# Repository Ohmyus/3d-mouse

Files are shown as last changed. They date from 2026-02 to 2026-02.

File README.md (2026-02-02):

# 3d-mouse

This project contains the files, software and instructions to build your own 3D CAD mouse. This is a device that allows for seamless 6-DOF navigation on any popular CAD software, however, the commercial options are quite pricy, so we took it in or own hands to make a (much cheaper, at about 20€) DIY option, that works just like the 150€ product. If you are a maker that spends a lot of time in CAD, or work with CAD professionally, consider making yourself one of these!

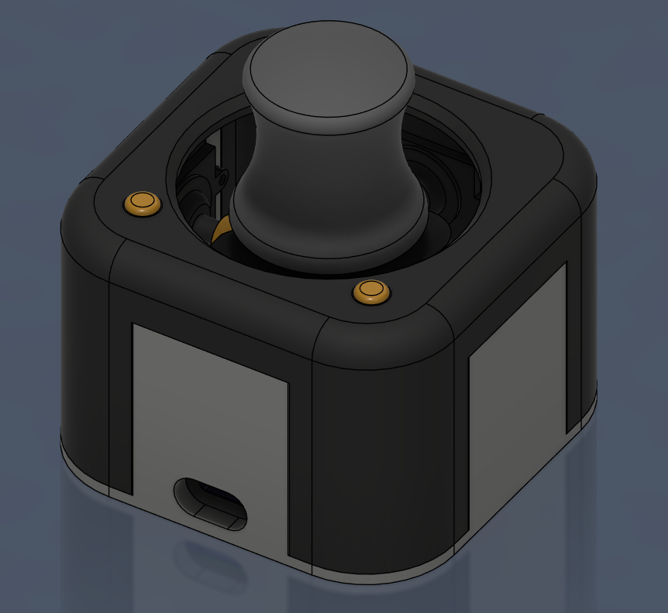
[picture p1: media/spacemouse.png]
Spacemouse


This spacemouse is a self-contained project. You are free to copy, modify, or add to it as you wish, as long as you credit its authors.

This project builds on [this](https://www.printables.com/model/864950-open-source-spacemouse-space-mushroom-remix) iteration of a 3D CAD mouse, by Teaching Tech. What we've done is created a new, smaller design, based on [these smaller joysticks](https://es.aliexpress.com/item/1005007021831547.html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) from the oculus controller. To interface with these joysticks, a PCB has been designed as well, that allows easier connection management, and the .grbr files are provided.

## Status:

A first prototype has been built, confirming that the PCB design is solid. All 6-DOF movements create their intended effect and allow for 3D navigation. No effort has been made yet to integrate the pushbuttons.

## Bill of Materials:

For each device that is built, the needed materials are:

 | Nº | Element | Quantity | Shopping link |
 | ---| ------- | -------- | ------------- |
 | 1  | Arduino Pro Micro | 1 | missing link |
 | 2  | Spacemouse PCB | 1 | missing link |
 | 3  | 3D printed parts | All | missing link |
 | 4  | 0.5 mm pitch, 5-pin ZIF connector | 4 | missing link |
 | 5  | Oculus Quest Joystick | 4 | missing link |
 | 6  | Wire | ~30 cm | missing link |
 | 7  | 6x6x4.3 mm pushbutton | 1 to 4 (user choice) | missing link |
 | 8  | 2-pin magnetic pogo connector| as many as pushbuttons | missing link |
 | 9  | USB cable (Arduino-Computer) | 1 | missing link |

## Build Instructions:
This section is still WIP. If possible, pictures will be added. Feedback is welcome.

## Required Tools:

- 3D printer (or the 3D printed parts)
- Soldering Iron
- Soldering flux
- Soldering Wick
- Tweezers (optional but *strongly* recommended)
- A computer that can flash an Arduino

### PCB & Electronics Assembly:
1.  Start by soldering all ZIF connectors to the PCB. The best results are obtained by using a lot of soldering flux and tin, and then removing the excess with a wick.  
  It is important to do this step first, because later on access will be lost to the nº 1 connector after soldering the Arduino.  
  It is recommended to test the soldering of the connectors with a multimeter in continuity mode.
2. Solder the arduino so that it is on the same side as the connectors, and the USB port is facing outside the PCB. 
3. Solder about 3cm wires to the pogo-pin connectors.
4. Solder about 4cm wires to the 6x6 mm pushbuttons.

### Mouse Assembly:
1. Mount the balljoint pieces on the joysticks. Be careful not to damage their cables.
2. Connect the joysticks to the PCB, so that the joysticks are facing the side opposite the Arduino.
3. (OPTIONAL) Add some small weights to the 3D printed bottom part. 
4. Carefully mount the PCB and the joysticks to the 3D printed bottom part. 
5. Mount the pogo-pin connectors to the 3D printed bottom part
6. Solder the connector cables to the PCB.

7. Put in the 3D printed top part the heat inserts for the buttons that you wish to use. 
8. Mount the pushbuttons to the 3D printed top part, by using the 3D printed button holder pieces.
9. Solder the pogo-pin connectors to the pushbutton cables
10. Mount the pogo-pin connectos to the 3D printed top part.

11. Mount the knob assembly (...)
12. Carefully lift the PCB from the bottom part, and mount the knob assembly.

13. Place the 3D printed top part on top of the 3D printed bottom part.

## Software Instructions:
### Installing the 3D Connexion Software
Go to 3D Connexion's [software download page](https://3dconnexion.com/us/drivers/) and download the appropriate software for your computer.

### Installing the Arduino IDE
1. Go to Arduino's [software page](https://www.arduino.cc/en/software/).
2. Select the IDE's version that matches your computer (eg: Windows, Linux).
3. Download and run the installation wizard.

### Flashing the Arduino Code
1. Create a new Arduino AVR board:  
2. Find your sketchbook folder by checking in the Arduino IDE File/Preferences, where your sketchbook folder is. It typically is `C:/Users/YOUR_USER/Documents/Arduino`.  
3. Create a new folder named `hardware`. Copy the spacemouse folder from this repo inside `hardware`.
4. Restart the Arduino IDE
5. Plug in you Arduino Pro Micro
6. In the Arduino IDE go to Tools/Board and select `Arduino AVR Boards (in sketchbook) (spacemouse)/spacemouse`
7. Flash the code in `spacemouse-code`

And that should get you a fully working spacemouse!

---

## Known Issues:

As of now, no code has been written to send the state of the pushbuttons. We still don't know how to send that state over the USB HID protocol. However, all the axis are working.

## Instructions for contributors:

1. Remember to export the 3D mouse design as a `.step` file. 
2. Always document the changes you make to the sketches.

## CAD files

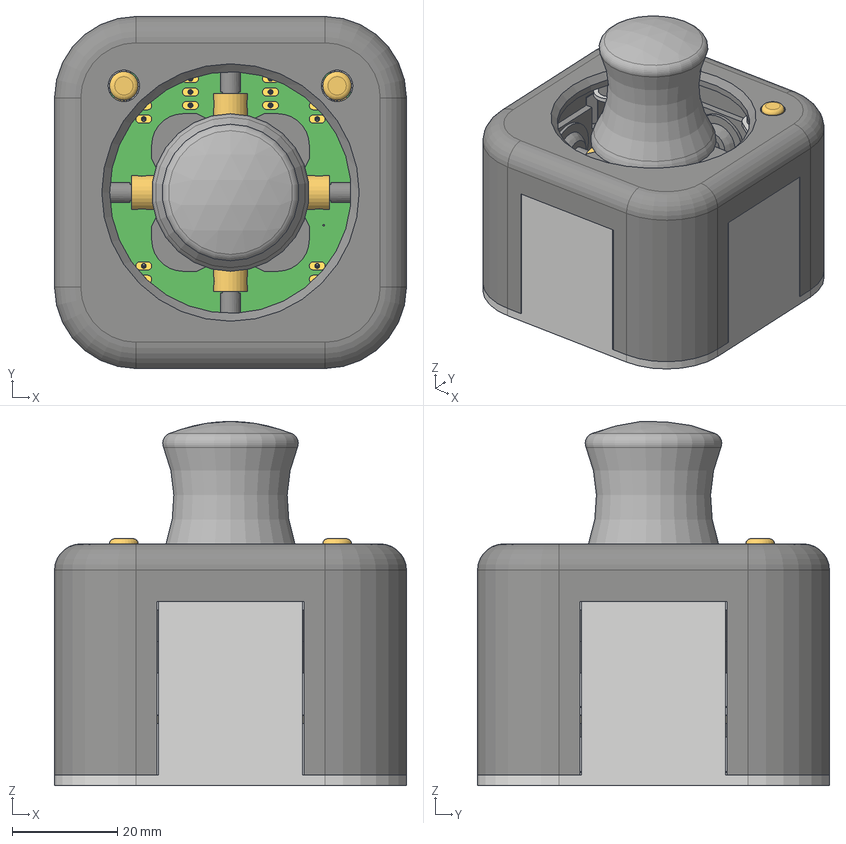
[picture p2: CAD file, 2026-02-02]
3D-files (updated)/SpacemouseFULL.step
67.0 x 67.0 x 69.3 mm
Joysitck x 4
BallJoint x 4
Knob
Board
1X02 x 4
1X12 x 2
1-copper
16-copper
1-soldermask
16-soldermask
Arduino_pro_micro

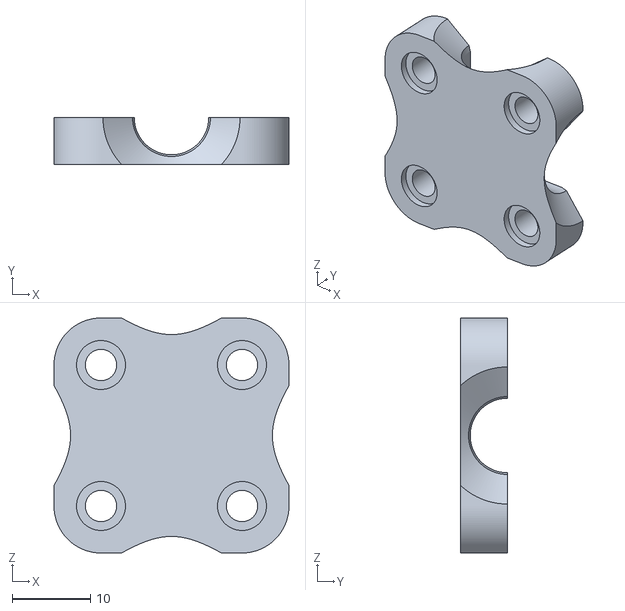
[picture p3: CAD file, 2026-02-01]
STL models/Bottom.stl
30.0 x 6.00 x 30.0

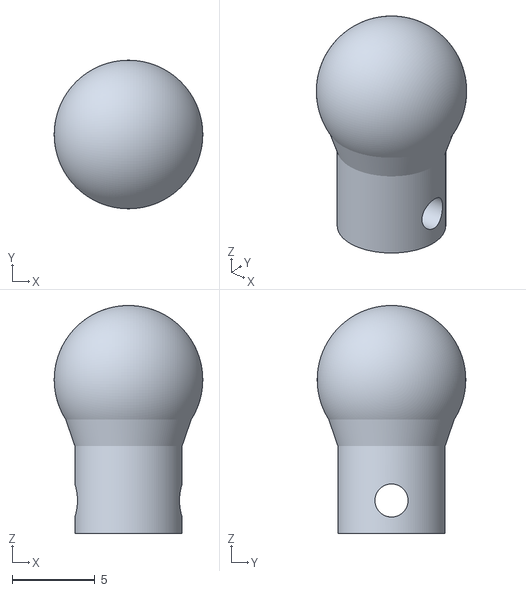
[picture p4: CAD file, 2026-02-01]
STL models/BallJoint.stl
9.00 x 9.00 x 13.8

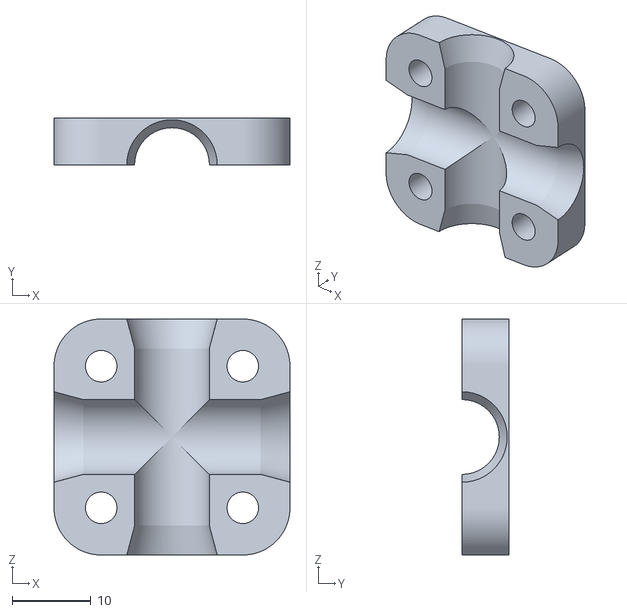
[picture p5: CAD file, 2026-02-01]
STL models/Top.stl
30.0 x 6.00 x 30.0

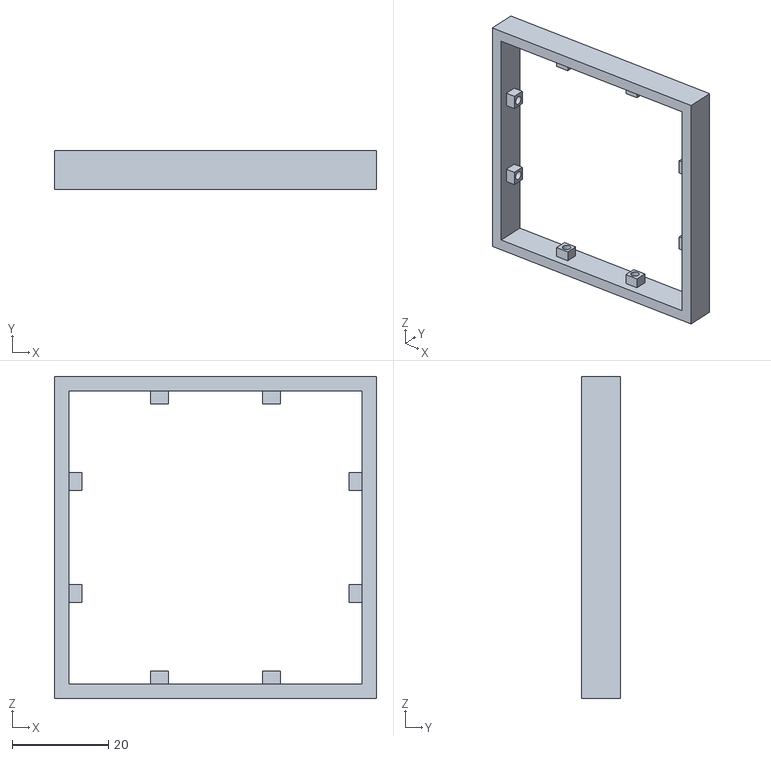
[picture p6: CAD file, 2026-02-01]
STL models/CasePrototy.stl
66.8 x 8.00 x 66.8

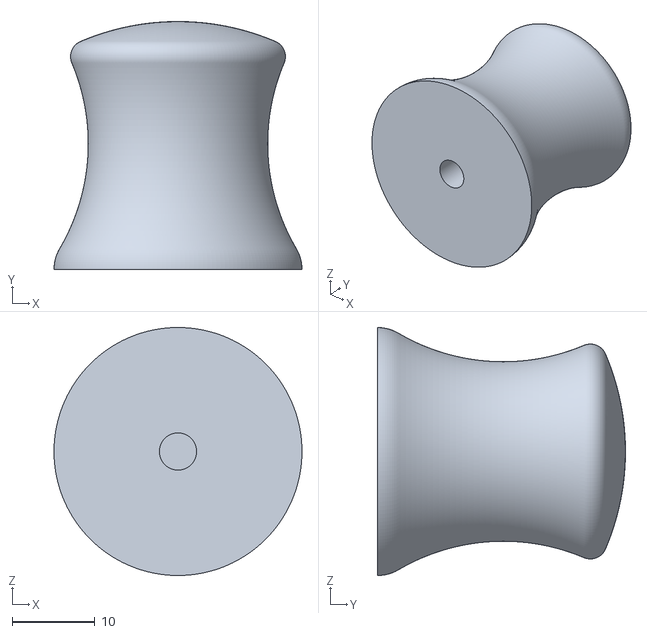
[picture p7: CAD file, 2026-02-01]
STL models/KnobTop.stl
30.0 x 30.0 x 30.0

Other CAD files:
STL models/KnobHandle.stl
STL models (old)/KnobTop.stl

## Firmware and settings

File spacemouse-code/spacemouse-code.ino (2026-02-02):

// Code to emulate a 3DConnexion Space Mouse by jfedor: https://pastebin.com/gQxUrScV

// Include inbuilt Arduino HID library by NicoHood: https://github.com/NicoHood/HID 
#include "HID.h"

// Debugging
// 0: Debugging off. Set to this once everything is working.
// 1: Output raw joystick values. 0-1023 raw ADC 10-bit values
// 2: Output centered joystick values. Values should be approx -500 to +500, jitter around 0 at idle.
// 3: Output centered joystick values. Filtered for deadzone. Approx -500 to +500, locked to zero at idle.
// 4: Output translation and rotation values. Approx -800 to 800 depending on the parameter.
// 5: Output debug 4 and 5 side by side for direct cause and effect reference.
int debug = 0;

// Deadzone to filter out unintended movements. Increase if the mouse has small movements when it should be idle or the mouse is too senstive to subtle movements.
int DEADZONE = 40;
// Speed
// Modify to change sensitibity/speed. Default and maximum 100. Works like a percentage ie. 50 is half as fast as default. This can also be done per application in the 3DConnexion software.
int16_t speed = 80;

// Direction
// Modify the direction of translation/rotation depending on preference. This can also be done per application in the 3DConnexion software.
// Switch between true/false as desired.
bool invX = false; // pan left/right
bool invY = false; // pan up/down
bool invZ = false; // zoom in/out
bool invRX = false; // Rotate around X axis (tilt front/back)
bool invRY = true; // Rotate around Y axis (tilt left/right)
bool invRZ = true; // Rotate around Z axis (twist left/right)

// Default Assembly when looking from above:
//   USB-C
//    C           Y+
//    |           .
// B--+--D   X-...Z+...X+
//    |           .
//    A           Y-
//
// Wiring. Matches the Spacemouse PCB by P. M. & R. P., meant to house the Arduino Pro Micro (atmega32u4)
int PINLIST[8] = { // The positions of the reads
  A8, // X-axis A
  A9, // Y-axis A
  A3, // X-axis B
  A10,// Y-axis B
  A0, // X-axis C
  A1, // Y-axis C
  A7, // X-axis D
  A6  // Y-axis D
};

// This portion sets up the communication with the 3DConnexion software. The communication protocol is created here.
// hidReportDescriptor webpage can be found here: https://eleccelerator.com/tutorial-about-usb-hid-report-descriptors/ 
static const uint8_t _hidReportDescriptor[] PROGMEM = {
  0x05, 0x01,           //  Usage Page (Generic Desktop)
  0x09, 0x08,           //  0x08: Usage (Multi-Axis)
  0xa1, 0x01,           //  Collection (Application)
  0xa1, 0x00,           // Collection (Physical)
  0x85, 0x01,           //  Report ID
  0x16, 0x00, 0x80,     //logical minimum (-500)
  0x26, 0xff, 0x7f,     //logical maximum (500)
  0x36, 0x00, 0x80,     //Physical Minimum (-32768)
  0x46, 0xff, 0x7f,     //Physical Maximum (32767)
  0x09, 0x30,           //    Usage (X)
  0x09, 0x31,           //    Usage (Y)
  0x09, 0x32,           //    Usage (Z)
  0x75, 0x10,           //    Report Size (16)
  0x95, 0x03,           //    Report Count (3)
  0x81, 0x02,           //    Input (variable,absolute)
  0xC0,                 //  End Collection
  0xa1, 0x00,           // Collection (Physical)
  0x85, 0x02,           //  Report ID
  0x16, 0x00, 0x80,     //logical minimum (-500)
  0x26, 0xff, 0x7f,     //logical maximum (500)
  0x36, 0x00, 0x80,     //Physical Minimum (-32768)
  0x46, 0xff, 0x7f,     //Physical Maximum (32767)
  0x09, 0x33,           //    Usage (RX)
  0x09, 0x34,           //    Usage (RY)
  0x09, 0x35,           //    Usage (RZ)
  0x75, 0x10,           //    Report Size (16)
  0x95, 0x03,           //    Report Count (3)
  0x81, 0x02,           //    Input (variable,absolute)
  0xC0,                 //  End Collection
 
  0xa1, 0x00,           // Collection (Physical)
  0x85, 0x03,           //  Report ID
  0x15, 0x00,           //   Logical Minimum (0)
  0x25, 0x01,           //    Logical Maximum (1)
  0x75, 0x01,           //    Report Size (1)
  0x95, 32,             //    Report Count (24)
  0x05, 0x09,           //    Usage Page (Button)
  0x19, 1,              //    Usage Minimum (Button #1)
  0x29, 32,             //    Usage Maximum (Button #24)
  0x81, 0x02,           //    Input (variable,absolute)
  0xC0,
  0xC0
};

// Axes are matched to pin order.
#define AX 0
#define AY 1
#define BX 2
#define BY 3
#define CX 4
#define CY 5
#define DX 6
#define DY 7

//Declaration of arrays to be populated during setup and runtime routines:
int centerPoints[8], rawReads[8], centered[8]; //moved here from loop declaration to avoid memory overhead

//Final movement variables:
int16_t transX, transY, transZ, rotX, rotY, rotZ; // Declare movement variables as 16 bit integers

// Helper function to read and store analogue voltages for each joystick axis.
void readAllFromJoystick(int *rawReads){
  for(int i=0; i<8; i++){
    rawReads[i] = analogRead(PINLIST[i]);
  }
}

void setup() {
  // HID protocol is set.
  static HIDSubDescriptor node(_hidReportDescriptor, sizeof(_hidReportDescriptor));
  HID().AppendDescriptor(&node);
  
  if (debug != 0) { // Begin Seral for debugging if there is a debug mode on
    Serial.begin(250000);
    delay(100);
  }

  // Read idle/centre positions for joysticks, and save it to the centerPoints variable.
  readAllFromJoystick(centerPoints);
}

// Function to send translation and rotation data to the 3DConnexion software using the HID protocol outlined earlier. Two sets of data are sent: rotation and then translation.
// For each, a 16bit integer is split into two using bit shifting. The first is mangitude and the second is direction.
void send_command(int16_t rx, int16_t ry, int16_t rz, int16_t x, int16_t y, int16_t z) {
  uint8_t trans[6] = { x & 0xFF, x >> 8, y & 0xFF, y >> 8, z & 0xFF, z >> 8 };
  HID().SendReport(1, trans, 6);
  uint8_t rot[6] = { rx & 0xFF, rx >> 8, ry & 0xFF, ry >> 8, rz & 0xFF, rz >> 8 };
  HID().SendReport(2, rot, 6);
}

void loop() {
  // Joystick values are read. 0-1023
  readAllFromJoystick(rawReads);
  // Report back 0-1023 raw ADC 10-bit values if enabled
  if(debug == 1){ 
    print_joystick_values(rawReads);
    Serial.print("\n"); //manually go to the next line
  }

  // Subtract centre position from measured position to determine movement.
  for(int i=0; i<8; i++) centered[i] = rawReads[i] - centerPoints[i]; // 
  // Report centered joystick values if enabled. Values should be approx -500 to +500, jitter around 0 at idle.
  if(debug == 2){
    print_joystick_values(centered);
    Serial.print("\n"); //manually go to the next line
  }
  // Filter movement values. Set to zero if movement is below deadzone threshold.
  for(int i=0; i<8; i++){
    if(centered[i]<DEADZONE && centered[i]>-DEADZONE) centered[i] = 0;
  }
  // Report centered joystick values. Filtered for deadzone. Approx -500 to +500, locked to zero at idle
  if(debug == 3){
    print_joystick_values(centered);
    Serial.print("\n"); //manually go to the next line
  }

  // Doing all through arithmetic contribution by fdmakara
  // Original fdmakara calculations
  //transX = (-centered[AX] +centered[CX])/1;
  //transY = (-centered[BX] +centered[DX])/1;
  //transZ = (-centered[AY] -centered[BY] -centered[CY] -centered[DY])/2;
  //rotX = (-centered[AY] +centered[CY])/2;
  //rotY = (+centered[BY] -centered[DY])/2;
  //rotZ = (+centered[AX] +centered[BX] +centered[CX] +centered[DX])/4;
  // My altered calculations based on debug output. Final divisor can be changed to alter sensitivity for each axis.
  transX = (centered[CX] - centered[AX])/2;  
  transY = (centered[DX] - centered[BX])/2;  
  transZ = -(centered[AY] + centered[BY] + centered[CY] + centered[DY])/4;
  rotX = (centered[CY] - centered[AY])/2;
  rotY = (centered[BY] - centered[DY])/2;
  rotZ = -(centered[AX] +centered[BX] +centered[CX] +centered[DX])/4;

// Alter speed to suit user preference
  transX = (transX * speed)/100;
  transY = (transY * speed)/100;
  transZ = (transZ * speed)/100;
  rotX = (rotX * speed)/100;
  rotY = (rotY * speed)/100;
  rotZ = (rotZ * speed)/100;
// Invert directions if needed
  if(invX == true){ transX = transX*-1;};
  if(invY == true){ transY = transY*-1;};
  if(invZ == true){ transZ = transZ*-1;};
  if(invRX == true){ rotX = rotX*-1;};
  if(invRY == true){ rotY = rotY*-1;};
  if(invRZ == true){ rotZ = rotZ*-1;};

// Report translation and rotation values if enabled. Approx -800 to 800 depending on the parameter.
  if(debug == 4){
    print_rotations();
    Serial.print("\n"); //manually go to the next line
  }
// Report debug 4 and 5 info side by side for direct reference if enabled. Very useful if you need to alter which inputs are used in th arithmatic above.
  if(debug == 5){
    print_joystick_values(centered);
    Serial.print("||");
    print_rotations();
    Serial.print("\n"); //manually go to the next line
  }

// Send data to the 3DConnexion software.
// The correct order was determined after trial and error
  send_command(rotX, rotY, rotZ, transX, transY, transZ);
  
}// End of loop()

// HELPER FUNCTIONS:
void print_joystick_values(int *array) {
  Serial.print("AX:");
  Serial.print(array[0]);
  Serial.print(",");
  Serial.print("AY:");
  Serial.print(array[1]);
  Serial.print(",");
  Serial.print("BX:");
  Serial.print(array[2]);
  Serial.print(",");
  Serial.print("BY:");
  Serial.print(array[3]);
  Serial.print(",");
  Serial.print("CX:");
  Serial.print(array[4]);
  Serial.print(",");
  Serial.print("CY:");
  Serial.print(array[5]);
  Serial.print(",");
  Serial.print("DX:");
  Serial.print(array[6]);
  Serial.print(",");
  Serial.print("DY:");
  Serial.print(array[7]);
}

void print_rotations() {//Uses global variables to improve readability
  Serial.print("TX:");
  Serial.print(transX);
  Serial.print(",");
  Serial.print("TY:");
  Serial.print(transY);
  Serial.print(",");
  Serial.print("TZ:");
  Serial.print(transZ);
  Serial.print(",");
  Serial.print("RX:");
  Serial.print(rotX);
  Serial.print(",");
  Serial.print("RY:");
  Serial.print(rotY);
  Serial.print(",");
  Serial.print("RZ:");
  Serial.print(rotZ);
}

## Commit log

2026-02-01 Add setup instructions for Spacemouse project
    Added instructions for setting up the Spacemouse project in Arduino IDE.
2026-02-01 Added 3D files, board files and main code
    [BallJoint.stl, Base.stl, Bottom.stl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]
2026-02-02 added grbr files and deprecated stls
    [BallJoint.stl, Base.stl, Bottom.stl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]
2026-02-02 added finally added 3D files and completed BOM
    [SpacemouseFULL.step]
2026-02-02 updated 3D model and added readme instructions
    [SpacemouseFULL.step]
2026-02-02 updated spacemouse code and fixed formatting in readme
    [spacemouse-code.ino]
